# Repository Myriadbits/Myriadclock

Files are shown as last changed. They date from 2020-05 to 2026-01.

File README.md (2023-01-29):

# Myriadclock
16x16 LED word clock with weekday and calender
Multilanguage and fully color customizable.

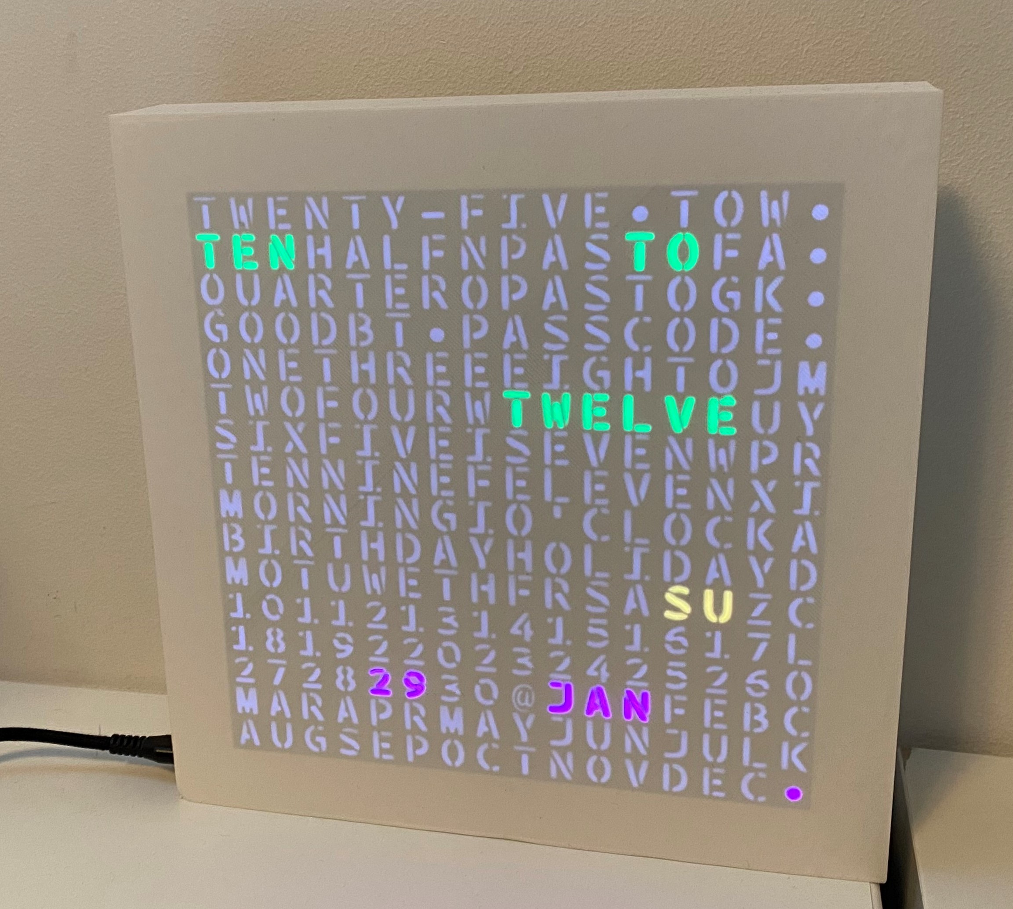
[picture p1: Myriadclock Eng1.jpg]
Englisch clock


## Printing directives
### Grid
*BLACK, PLA, 11 hours, 38 minutes, +- 20 meter (61g)*

Just normal settings, `standard quality`. No need for supports, no infill. Use a brim if desired. Print with the open top of the Y stutts to the top. This way the bottom will be very smooth and there is no light leakage between base plate and the grid.

### Casing
*WHITE, PLA, 18 hours, 13 minutes, +- 44 meter (132g)*

Casing is large (20x20cm) so there might not be space to add the adhesion skirt or brim (at least on my Ender3). So please set `Build plate adhesion type` to `None`. 
To get a nice front panel, it is essential that the `bottom thickness` is at least 4 layers or else you will see the infill instead of the characters in the clock. Set the `top thickness` to 4 as well to avoid seeing the infill at the back of the clock. An infill of 20% is enough. 
Some supports are needed, for the wire hole and the PCB holder. I prefer to set `Support Structure` to `Tree` since the tree's are rather easy to remove.
The casing should be printed in white since the white is partly transparent and will make the characters of the word clock shine through.
Rather obvious, but print the casing with the open part to the top. 
Infill pattern: Cubic, 20%

### Backplane
*WHITE PLA, 9 hours, 50 minutes, +- 27 meter (80g)*

Rotate the backplane UPSIDE-DOWN (flat part down)!
My initial version was printed with only 2 top and 2 bottom layers but that way you can see the infill, so it would be better to just use the default `standard quality`. 
No supports needed, build skirt can be printed.

### Clamp(s)
*3x PLA (Color does not matter), 51 minutes, +- 2 meter (6g)*

Rotate the clamp to it's side top print without supports!
This is used to hold the LED panel on top of the grid, you will probably need 3 clamps. 
Normal print settings, `standard quality` is fine.

### Character plate
*BLACK PLA, 6 hours 34 minutes, +- 8 meter (26g)*

For best result: Print the plate UPSIDE-DOWN. That way the smooth part will be touching the casing.
Print this in black. The plate is only 5 layers tick, all layers should be printed. You might want to tweak some setting to prevent holes getting accidentally be filled with debris/hairs/wires (allthough I didn't find the correct setting for that yet...)
Travel-Combining mode: All
Retract at layer change: True
Z Hop Height: 0.4
Avoid printed parts when travelling: False (I rather not travel over the holes!)

PLA: 105m (for me that is approx €6)

## Components

### LED Panel

WS2812B LED Panel 16x16
Matrix SK6812 WS2812B Panel Flexible 5050 RGB 8x8 8x32 16x16 Pixels Digital Sreen Display Light GyverLamp SP107E LC1000A Kit
https://www.aliexpress.com/item/32875701384.html?spm=a2g0s.9042311.0.0.27424c4dam1nq0
*Buy the WS2812B 16x16 only*

Approx €10 (depends on supplier and shipping fees)

### ESP32 Module
4 MB Flash For WeMos D1 ESP32 ESP-32 ESP-32S ESP32S Wifi Bluetooth Wireless Module Based ESP-WROOM-32 Dual Core Mode CP
https://www.aliexpress.com/item/32917886231.html?spm=a2g0s.9042311.0.0.11af4c4drBH1TU

Approx €4 (depends on supplier and shipping fees)

Total costs (without electricity): +- €20

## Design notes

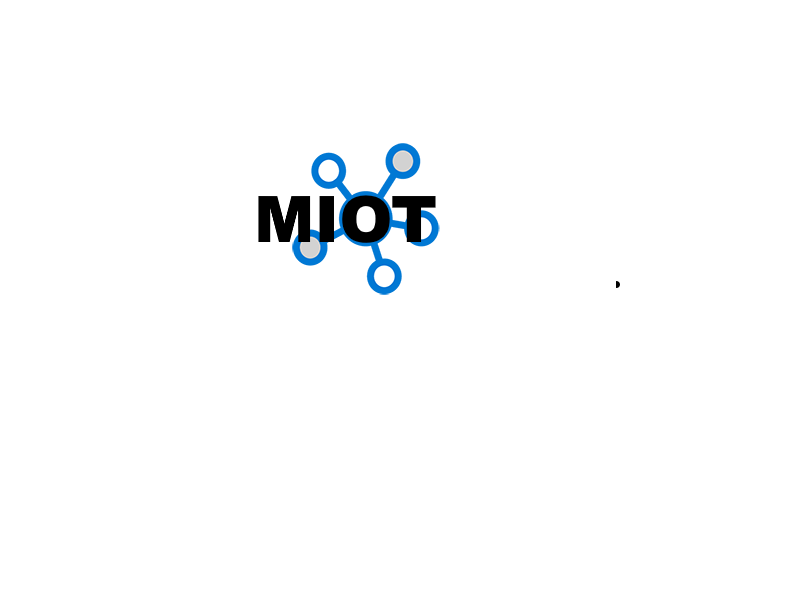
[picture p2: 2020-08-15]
documentation/MIOT.png

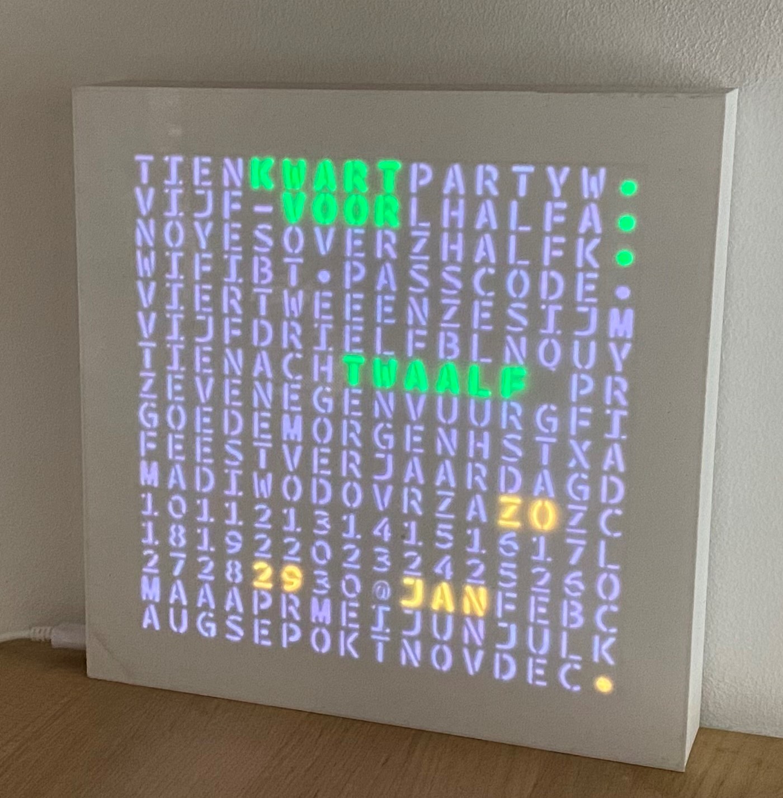
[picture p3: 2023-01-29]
documentation/Myriadclock2.jpg

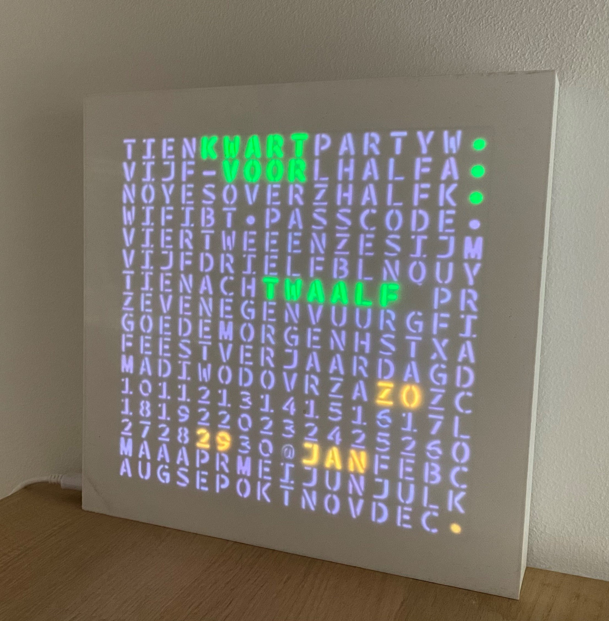
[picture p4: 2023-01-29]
documentation/Myriadclock1.jpg

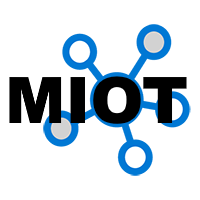
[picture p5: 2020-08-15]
documentation/MIOT2.png

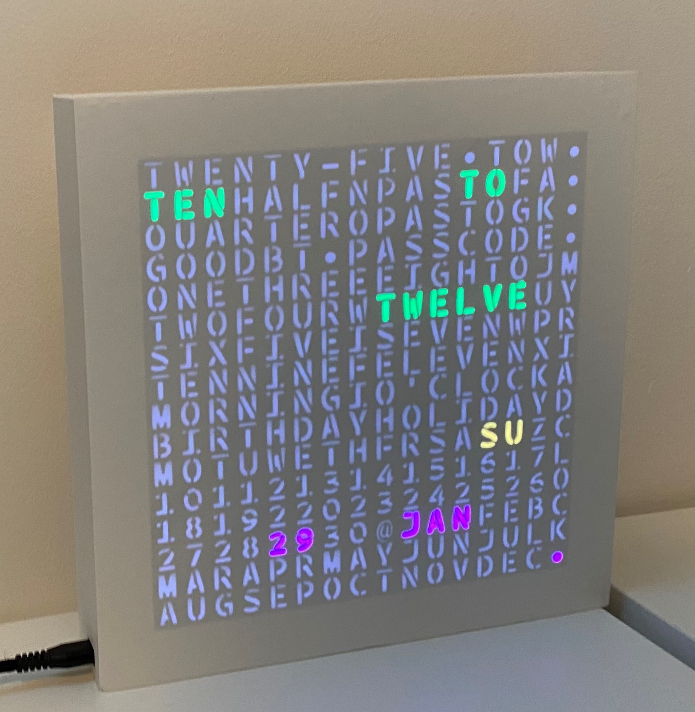
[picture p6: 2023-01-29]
documentation/Myriadclock Eng2.jpg

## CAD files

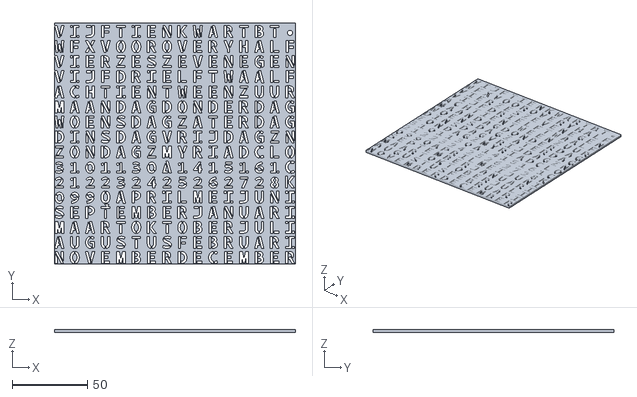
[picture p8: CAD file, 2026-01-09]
stl files/MyriadClock Chars NL v2.stl
160.0 x 160.0 x 2.00

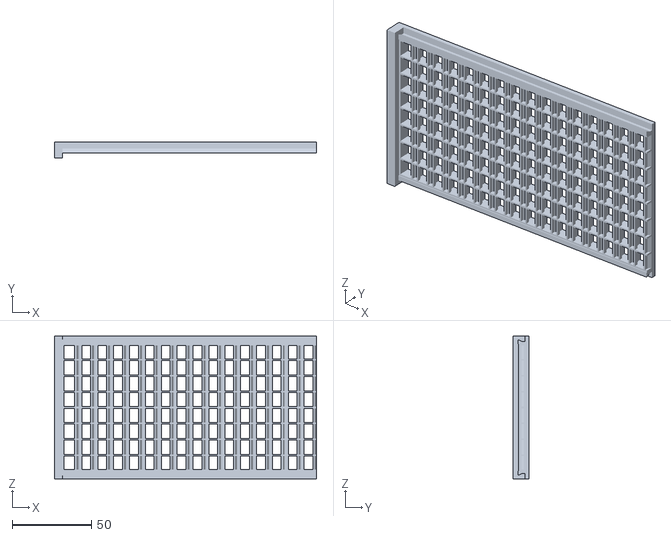
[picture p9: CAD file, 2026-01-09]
stl files/Cloxel_Mask_1.stl
165.0 x 9.90 x 90.0

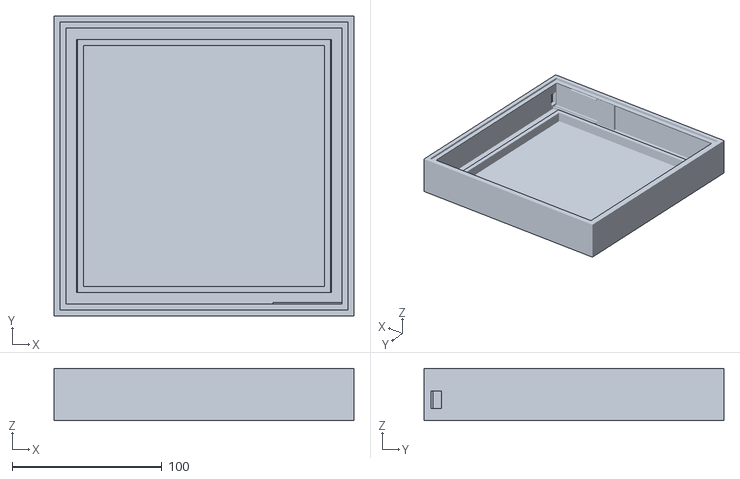
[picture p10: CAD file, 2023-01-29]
stl files/Casing.stl
200.0 x 200.0 x 35.0

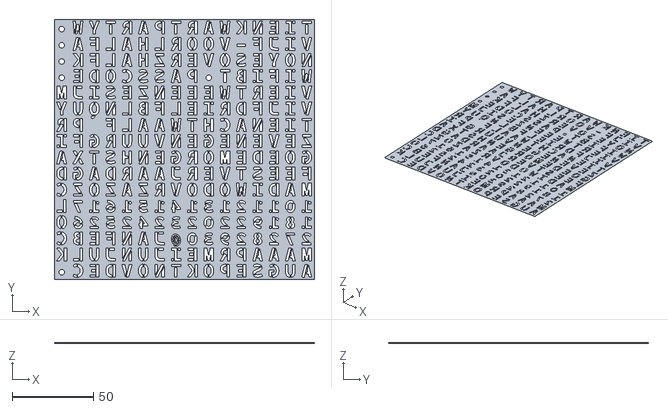
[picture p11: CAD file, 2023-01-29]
stl files/Plate NL V2.01.stl
160.4 x 160.4 x 0.6

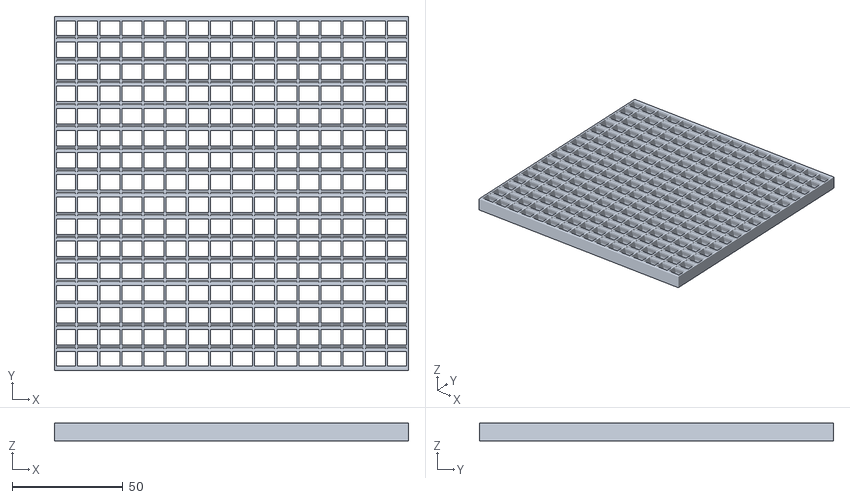
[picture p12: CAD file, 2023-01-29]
stl files/Grid.stl
160.0 x 160.0 x 8.00

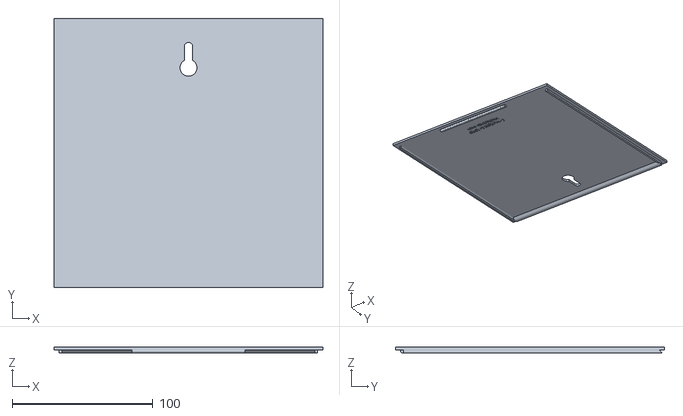
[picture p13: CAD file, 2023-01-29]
stl files/Backplane.stl
191.2 x 191.2 x 4.00

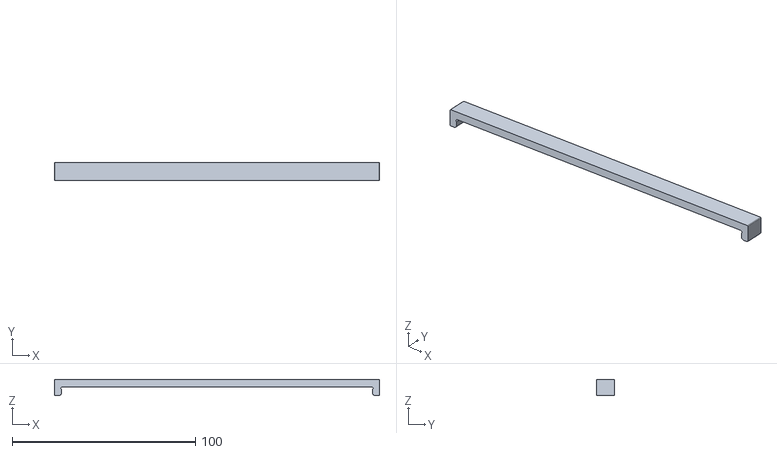
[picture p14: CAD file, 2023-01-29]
stl files/Clamp.stl
177.4 x 10.0 x 8.80

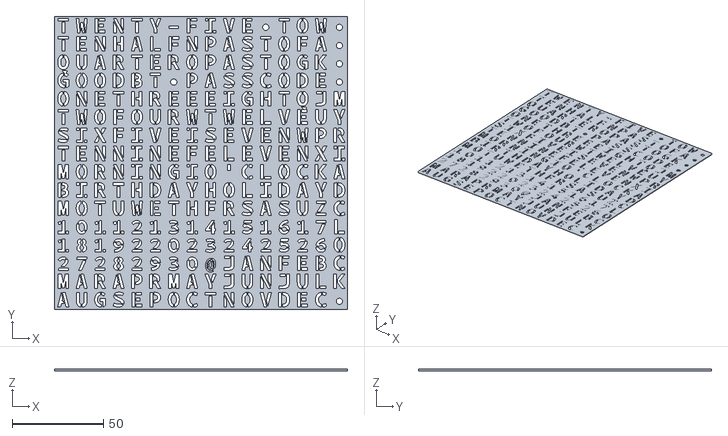
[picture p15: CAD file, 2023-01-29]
stl files/Plate EN V1.01.stl
160.4 x 160.4 x 1.00

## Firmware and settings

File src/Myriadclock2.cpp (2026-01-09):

/*  Myriadclock
    Using WS2812 LED Panel

    Created by Jochem Bakker

    This code is in the public domain...

    You can: copy it, use it, modify it, share it or just plain ignore it!
    Thx!

    NTPClient: https://github.com/arduino-libraries/NTPClient
        //Disabled:    Autoconnect stuff: https://github.com/Hieromon/AutoConnect
    TimeZone: https://github.com/JChristensen/Timezone
    Esp32FOTA: https://github.com/chrisjoyce911/esp32FOTA

    Colors:
    https://sashat.me/2017/01/11/list-of-20-simple-distinct-colors/
*/

#include <NTPClient.h>
#include <WiFi.h>
#include <time.h>
#include <Timezone.h>

#include "../lib/BLEConfig/include/BLEConfig.h"

#include "Console.h"
#define FASTLED_INTERNAL
#include <FastLED.h>       // Fastled library to control the LEDs

#include "DisplayStateManager.h"
#include "MyriadclockConfig.h"
#include <ArduinoJson.h>

#define MYRIADCLOCK_MANUFACTURER    "www.cloxel.nl"
#define MYRIADCLOCK_MODEL           "Wordcloxel"
#define MYRIADCLOCK_VERSION         "2.1.0"
#define MYRIADCLOCK_DEFAULTNAME     "Wordcloxel"
#define MYRIADCLOCK_DEFAULTLOCATION "Default room"


// Pin defines
#define DATA_PIN                13      // Connected to the data pin of the first LED strip
#define RECEIVER_PIN            22      // RXB6 input pin
#define TYPE_PIN                17      // Pin for determining the type of the board
#define NUM_LEDS                256

using namespace std;


static CRGB         g_Leds[NUM_LEDS]; // Define the array of leds
static uint32_t     g_timestamp  = 0;
static uint32_t     g_timeCounter = 0;
static bool         g_fNTPStarted = false;
static int          g_nPreviousHour = 0;

WiFiUDP             g_ntpUDP;

// Manager containing all display state related functionality
DisplayStateManager g_stateManager;

// By default 'pool.ntp.org' is used with 60 seconds update interval and no offset
NTPClient           g_timeClient(g_ntpUDP, "pool.ntp.org");

// The BLE Config library
BLEConfig           g_bleconfig(MYRIADCLOCK_MODEL, MYRIADCLOCK_MANUFACTURER, MYRIADCLOCK_VERSION, 256); // 256 = Clock TODO VERSION

//
// Setup all hardware
//
void setup() 
{
    // Create + start the console
    Console::getInstance().start(115200);   

    // Determine the board type/capabilities
    pinMode(TYPE_PIN, INPUT_PULLDOWN);  // set pin as input
    //Serial.printf("Type: %d\n", digitalRead(TYPE_PIN)); 

	FastLED.addLeds<NEOPIXEL, DATA_PIN>(g_Leds, NUM_LEDS); // Init of the Fastled library
	FastLED.setBrightness(100);  // Don't set it too bright our clock can't handle that power

    // Load/initialize all BLE Config settings
    g_bleconfig.registerWifi(CONFIG_WIFI, "WiFi SSID");

    //g_bleconfig.registerString(CONFIG_LOCATION, "Location", std::string(MYRIADCLOCK_DEFAULTLOCATION), true);

    BLEConfigItemOption *pconfig = g_bleconfig.registerOption(CONFIG_LAYOUT, "Clock layout", 3);
    pconfig->addOption((uint8_t) 0, "Dutch V2");
    pconfig->addOption((uint8_t) 1, "Dutch V1");
    pconfig->addOption((uint8_t) 2, "English"); 
    pconfig->addOption((uint8_t) 3, "Dutch V3");
    pconfig->addOption((uint8_t) 4, "English V2");
    pconfig->addOption((uint8_t) 5, "Cloxel"); 
    
    pconfig = g_bleconfig.registerOption(CONFIG_DAYLIGHTSAVING, "Daylight saving zone", 0);
    pconfig->addOption((uint8_t) 0, "Off"); 
    pconfig->addOption((uint8_t) 1, "Central European"); 
    pconfig->addOption((uint8_t) 2, "United Kingdom"); 
    pconfig->addOption((uint8_t) 3, "Australia");
    pconfig->addOption((uint8_t) 4, "US"); 
      
    pconfig = g_bleconfig.registerOption(CONFIG_TIMEZONE, "Timezone", 13);
    pconfig->addOption((uint8_t) 0, "-12"); 
    pconfig->addOption((uint8_t) 1, "-11"); 
    pconfig->addOption((uint8_t) 2, "-10");
    pconfig->addOption((uint8_t) 3, "-9");
    pconfig->addOption((uint8_t) 4, "-8"); 
    pconfig->addOption((uint8_t) 5, "-7"); 
    pconfig->addOption((uint8_t) 6, "-6"); 
    pconfig->addOption((uint8_t) 7, "-5"); 
    pconfig->addOption((uint8_t) 8, "-4"); 
    pconfig->addOption((uint8_t) 9, "-3"); 
    pconfig->addOption((uint8_t) 10, "-2"); 
    pconfig->addOption((uint8_t) 11, "-1"); 
    pconfig->addOption((uint8_t) 12, "0"); 
    pconfig->addOption((uint8_t) 13, "1"); 
    pconfig->addOption((uint8_t) 14, "2"); 
    pconfig->addOption((uint8_t) 15, "3"); 
    pconfig->addOption((uint8_t) 16, "4"); 
    pconfig->addOption((uint8_t) 17, "5"); 
    pconfig->addOption((uint8_t) 18, "6"); 
    pconfig->addOption((uint8_t) 19, "7"); 
    pconfig->addOption((uint8_t) 20, "8"); 
    pconfig->addOption((uint8_t) 21, "9"); 
    pconfig->addOption((uint8_t) 22, "10"); 
    pconfig->addOption((uint8_t) 23, "11"); 
    pconfig->addOption((uint8_t) 24, "12"); 

    g_bleconfig.registerRGBColor(CONFIG_COLOR_TIME, "Time color", 0x00FF00, true);
    g_bleconfig.registerRGBColor(CONFIG_COLOR_WEEKDAY, "Weekday Color", 0xFFA500, true);
    g_bleconfig.registerRGBColor(CONFIG_COLOR_DATE, "Date color", 0xE59400, true);
    g_bleconfig.registerRGBColor(CONFIG_COLOR_BACKGROUND, "Background color", 0xFFFFFF, true);   

    g_bleconfig.registerSlider(CONFIG_BRIGHTNESS_DAY, "Brightness Day", 80, false);
    g_bleconfig.registerSlider(CONFIG_BRIGHTNESS_NIGHT, "Brightness Night", 30, false);
    g_bleconfig.registerSlider(CONFIG_BRIGHTNESS_BACKGROUND, "Background Brightness", 4, false);

    pconfig = g_bleconfig.registerOption(CONFIG_OPTIONS_TIME, "Time color options", DO_STATIC);
    pconfig->addOption((uint8_t) DO_STATIC, "Manual");
    pconfig->addOption((uint8_t) DO_COLOR_CYCLENORMAL, "Color cycle");
    pconfig->addOption((uint8_t) DO_COLOR_CYCLEHOUR, "Color cycle hourly");
    pconfig->addOption((uint8_t) DO_COLOR_WEEK_AYURVEDA, "Ayurveda colors daily");
    pconfig->addOption((uint8_t) DO_COLOR_WEEK_THAI, "Thai colors daily");

    pconfig = g_bleconfig.registerOption(CONFIG_OPTIONS_WEEKDAY, "Weekday color options", DO_STATIC);
    pconfig->addOption((uint8_t) DO_STATIC, "Manual");
    pconfig->addOption((uint8_t) DO_COLOR_CYCLENORMAL, "Color cycle");
    pconfig->addOption((uint8_t) DO_COLOR_CYCLEHOUR, "Color cycle hourly");
    pconfig->addOption((uint8_t) DO_COLOR_WEEK_AYURVEDA, "Ayurveda colors daily");
    pconfig->addOption((uint8_t) DO_COLOR_WEEK_THAI, "Thai colors daily");

    pconfig = g_bleconfig.registerOption(CONFIG_OPTIONS_DATE, "Date color options", DO_STATIC);
    pconfig->addOption((uint8_t) DO_STATIC, "Manual");
    pconfig->addOption((uint8_t) DO_COLOR_CYCLENORMAL, "Color cycle");
    pconfig->addOption((uint8_t) DO_COLOR_CYCLEHOUR, "Color cycle hourly");
    pconfig->addOption((uint8_t) DO_COLOR_WEEK_AYURVEDA, "Ayurveda colors daily");
    pconfig->addOption((uint8_t) DO_COLOR_WEEK_THAI, "Thai colors daily");

    pconfig = g_bleconfig.registerCommandOption(CONFIG_COMMAND, "Custom commands");
    pconfig->addOption((uint8_t) UC_NORMAL, "Normal");
    pconfig->addOption((uint8_t) UC_MATRIX, "Matrix");
    pconfig->addOption((uint8_t) UC_ALLWORDS, "All words");
    pconfig->addOption((uint8_t) UC_ANALOG, "Analog");

    pconfig = g_bleconfig.registerOption(CONFIG_OPTIONS_CLOXEL, "Cloxel options", 0);
    pconfig->addOption((uint8_t) 0, "Date & time highfont"); 
    pconfig->addOption((uint8_t) 1, "Date & time"); 
    pconfig->addOption((uint8_t) 2, "Time & seconds"); 
    pconfig->addOption((uint8_t) 3, "Date & time & second block"); 
    //g_bleconfig.registerString(CONFIG_NAME, "Name", "enteryourname", false);


    // Start the BLE Config stuff
    // This will also load all previously stored settings
    g_bleconfig.start(&g_stateManager);

    // Initialize all display related functionality
    g_stateManager.initialize(g_Leds, &g_bleconfig);
}


//
// Main program loop
//
void loop() 
{
    // Handle RF 433 Mhz
    //g_rf.loop();   

    // TODO Make currentstate an ENUM
    g_stateManager.handleLoop(g_timeClient.getEpochTime());

    //g_server.handleClient();
        
    // And the console
    Console::getInstance().tick();    

    // Once every x seconds, check the NTP stuff
    uint32_t now = millis();
    if ((now - g_timestamp) > 1000)
    {                
        g_timestamp = now;

        if (WiFi.status() == WL_CONNECTED)
        {
            if (!g_fNTPStarted)
            {
                Serial.printf("Connected to: %s\n", WiFi.SSID().c_str());
                Serial.printf(" - IP address: %s\n", WiFi.localIP().toString().c_str());
                Serial.printf(" - Gateway: %s\n", WiFi.gatewayIP().toString().c_str());
                Serial.printf(" - Mask: %s\n", WiFi.subnetMask().toString().c_str());

                g_timeClient.begin();
                g_fNTPStarted = true;
            }
        }
        else
        {
            g_timeCounter++;
            if ((g_timeCounter % 30) == 0)
            {
                // Not connected anymore, try to reconnect
                Serial.printf("WiFi connection lost. Restarting WiFi\n");
                WiFi.disconnect();
                WiFi.reconnect();
            }
            
            if (g_fNTPStarted)
            {
                g_timeClient.end();
                g_fNTPStarted = false;
            }
        }
        
        if (g_fNTPStarted)
        {
            if (g_timeClient.update())
            {            
                // Check for 3->4 hour switch
                // Let Handle-Loop return another state
                // Convert to local time
                TimeChangeRule *tcr;    
                TimeChangeRule utcRule = {"UTC", Last, Sun, Mar, 1, 0};     // UTC
                Timezone UTC(utcRule);
                time_t t = UTC.toLocal(g_timeClient.getEpochTime(), &tcr); // (Note: tcr cannot be NULL)
                int hours = hour(t);
                int currentYear = year(t);

                if (currentYear > 1970 && g_nPreviousHour != hours)
                {
                    g_stateManager.setDefaultState(DS_CLOCK);
                }

                if (hours == 4 && g_nPreviousHour != 4)
                {
                    // Switch to updating
                    g_stateManager.changeState(DS_UPDATING);
                }
                g_nPreviousHour = hours;
            }
        }
    }   
}

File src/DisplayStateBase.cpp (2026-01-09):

///////////////////////////////////////////////////////////////////////////////
// DisplayStateBase class
// Base class for controlling the display/led states
///////////////////////////////////////////////////////////////////////////////

#include "DisplayStateBase.h"
#include "ClockLayoutNL_V1.h"
#include "Myriadbitsfont5x6_3.h"
#include "Myriadbitsfont5x8_3.h"
#include "HighFont4x8.h"
#include "HighFont4x6.h"

// For now assume the (0,0) of the dutch coordinate system 
#define CLOCK_LATITUDE      52.155194
#define CLOCK_LONGITUDE     5.387270
#define CLOCK_ALTITUDE      10

#define YEAR_2000_TIMESTAMP     946684800ULL
#define SECONDS_PER_HOUR        3600ULL
#define SECONDS_PER_DAY         86400ULL

ledclocklayout_t DisplayStateBase::s_layout = s_layoutNL_V1;

//
//  Return the elapsed time in milliseconds since a timestamp
//
uint32_t DisplayStateBase::Elapsed(uint32_t ts)
{
    uint32_t now = millis();
    if (ts < now) return (now - ts);
    return(now + (0xffffffff - ts));
}

//
// Return the led index in the leds array
//
int16_t DisplayStateBase::CalcLedPos(int8_t x, int8_t y)
{
    int pos = 0;
    if (s_layout.orientation == EOrientation::O_NORMAL)
    {
        if ((y % 2) == 0)
            pos = (s_layout.columns - x - 1) + (y * s_layout.columns); 
        else
            pos = x + (y * s_layout.columns); 
    }
    else
    {
        if ((x % 2) == 0)
            pos = y + (x * s_layout.rows); 
        else
            pos = (s_layout.rows - y - 1) + (x * s_layout.rows); 
    }
    return (pos % s_layout.numLeds);
}

//
// Set the clock layout
void DisplayStateBase::setLayout(const ledclocklayout_t *layout) 
{      
    memcpy(&s_layout, layout, sizeof(s_layout));    
};

//
// Color handler for words
CRGB DisplayStateBase::ColorHandler(CRGB defaultColor, int brightness, int customParam)
{
    return defaultColor.fadeLightBy(255 - brightness);
    //return defaultColor.nscale8_video(brightness);
}

//
// Add a single word to the display/leds
// customParam can be any value, normal operation when ColorHandler is not overriden: customParam is the color
void DisplayStateBase::AddWordToLeds(const ledpos_t *pCurrentWord, CRGB defaultColor, int brightness, int customParam) 
{
    if (pCurrentWord == NULL) return;
    if (m_pLEDs == NULL) return;

    uint8_t charIndex = 0;
    ledpos_t ledPos = pCurrentWord[charIndex];
    while (ledPos.x >= 0 && ledPos.y >= 0)
    {
        // Led numbers are inverted left to right every other row:        
        m_pLEDs[CalcLedPos(ledPos.x, ledPos.y)] = ColorHandler(defaultColor, brightness, customParam);
        
        // Next char
        charIndex++;
        ledPos = pCurrentWord[charIndex];
    }
}

//
// Fill the entire background with a color
void DisplayStateBase::FillBackground(const int brightness)
{
    // Set the background color
    if (brightness != 0)
    {
        CRGB colDefault = m_pConfig->getConfigValue(CONFIG_COLOR_BACKGROUND);

        CRGB rgbClear = ColorHandler(colDefault, brightness, 0);
        for(int n = 0; n < s_layout.numLeds; n++)
            m_pLEDs[n] = rgbClear;
    }
}


//
// @brief  Draw a character on the LED panel
//
void DisplayStateBase::DrawGFX(CRGB *pLEDs, EFontType fontType, ETextAlign align, int x, int y, std::string text, CRGB color)
{
    const GFXfont* pFont = NULL;
    switch (fontType)
    {
        case EFontType::FT_56: pFont = &JochemFont56; break;
        case EFontType::FT_HIGHFONT48: pFont = &Highfont4x8; break;
        case EFontType::FT_HIGHFONT46: pFont = &Highfont4x6; break;
        case EFontType::FT_582: pFont = &JochemFont58; break;
    }
    if (pFont == NULL)
        return;

    int posX = x;
    int posY = y;

    if ((align & ETextAlign::TA_HCENTER) != 0)
    {
        int sizeX = CalculateGFXWidth(pFont, text);
        posX = (s_layout.columns - sizeX) / 2;
    }
    if ((align & ETextAlign::TA_VCENTER) != 0)
    {
        int sizeY = pFont->glyph->height;
        posY = (s_layout.rows - sizeY) / 2;
    }
    if ((align & ETextAlign::TA_MIDTEXT) != 0)
    {
        int len = text.length();
        int sizeX = CalculateGFXWidth(pFont, text.substr(0, len/2));
        if ((len % 2) != 0)
        {
            // Uneven characters, so add half of the width of the center character
            int extra = (CalculateGFXWidth(pFont, text.substr(len/2, 1)) / 2);
            sizeX += extra;
        }
        posX = (s_layout.columns / 2) - sizeX;
    }
    if ((align & ETextAlign::TA_END) != 0)
    {
        int sizeX = CalculateGFXWidth(pFont, text);
        posX = (s_layout.columns - sizeX) - x + 1;
    }

    for(char ch: text)
    {
        if (ch >= pFont->first && ch < pFont->last)
        {
            char c = (ch - pFont->first);

            GFXglyph *glyph = &(pFont->glyph[c]);
            uint8_t *bitmap = pFont->bitmap;

            uint16_t bo = glyph->bitmapOffset;
            uint8_t w = glyph->width;
            uint8_t h = glyph->height;

            uint8_t bits = 0;
            uint8_t bit = 0;
            for (int yy = h - 1; yy >= 0; yy--)
            {
                for (int xx = 0; xx < w; xx++)
                {
                    if (bit == 0x00)
                    {
                        bits = bitmap[bo++];
                        bit = 0x80;
                    }
                    if (bits & bit)
                    {
                        pLEDs[CalcLedPos(posX + xx, posY + y + (h - 1 - yy))] = color;
                    }
                    bit = bit >> 1;
                }
            }
            posX += glyph->xAdvance;
        }
    }
}


/// @brief Calculate the width of an text
/// @param font 
/// @param text 
int DisplayStateBase::CalculateGFXWidth(const GFXfont* font, std::string text)
{
    int16_t xo16 = 0;
    for(char ch: text)
    {
        if (ch >= font->first && ch < font->last)
        {
            char c = (ch - font->first);
            GFXglyph *glyph = &(font->glyph[c]);
            xo16 += glyph->xAdvance;
        }
    }
    return xo16;
}


//
// Simple log function
void DisplayStateBase::log(const char* format, ...)
{
    static char sBuffer[256];
    va_list ap;
    va_start(ap, format);
    Serial.printf("[%s %lu] ", m_name.c_str(), millis());
    vsprintf(sBuffer, format, ap);
    Serial.println(sBuffer);
    va_end(ap);
}
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

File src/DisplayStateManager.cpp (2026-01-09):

///////////////////////////////////////////////////////////////////////////////
// StateManager class
// Class that manages all display states
///////////////////////////////////////////////////////////////////////////////

#include "DisplayStateManager.h"

#include "DisplayStateNoWiFi.h"
#include "DisplayStateBooting.h"
#include "DisplayStateWords.h"
#include "DisplayStateClock.h"
#include "DisplayStateUpdating.h"
#include "DisplayStatePasscode.h"
#include "DisplayStateMatrix.h"
#include "DisplayStateAnalog.h"

#include "ClockLayoutNL_V1.h"
#include "ClockLayoutNL_V2.h"
#include "ClockLayoutNL_V3.h"
#include "ClockLayoutEN_V1.h"
#include "ClockLayoutEN_V2.h"
#include "ClockLayoutNL_Cloxel.h"

#define STARTUP_TIME                10000 // X milliseconds startup time (before switching to no-wifi)
#define TIMEZONE_CHANGED_TIME        5000 // X milliseconds time after switching timezones

// Australia 
TimeChangeRule aEDT = {"AEDT", First, Sun, Oct, 2, 660};    // UTC + 11 hours
TimeChangeRule aEST = {"AEST", First, Sun, Apr, 3, 600};    // UTC + 10 hours

// US 


// UTC
TimeChangeRule utcRule = {"UTC", Last, Sun, Mar, 1, 0};     // UTC


// Fake reset function
void(* resetFunc) (void) = 0;//declare reset function at address 0

//
//  Initialize/setup this class
//
void DisplayStateManager::initialize(CRGB* pLEDs, BLEConfig* pConfig)
{ 
    m_pLEDs = pLEDs;
    m_pTZ = NULL;
    m_pConfig = pConfig;
    m_timezoneChangedCountdown = 0;

    // Add all states to our statemachine
    addState(DS_NOWIFI, new DisplayStateNoWiFi());
    addState(DS_BOOTING, new DisplayStateBooting());
    addState(DS_CLOCK,  new DisplayStateClock());
    addState(DS_WORDS, new DisplayStateWords());
    addState(DS_UPDATING, new DisplayStateUpdating());
    addState(DS_PASSCODE, new DisplayStatePasscode());
    addState(DS_MATRIX, new DisplayStateMatrix());
    addState(DS_ANALOG, new DisplayStateAnalog());

    Console::getInstance().add("state", this, "Switch the display state");
    Console::getInstance().add("layout", this, "Switch the layout");
    Console::getInstance().add("reset", this, "Reset");

    // Start the default state
    changeState(m_eDefaultState);

    // Load the last layout
    setLayout(m_pConfig->getConfigValue(CONFIG_LAYOUT));

    // And initialize the timezone
    setTimezone();
}

//
// Change/set the state
//
void DisplayStateManager::changeState(const EDisplayState eState)
{
    m_eNewState = eState;
}

//
// Add a new state to the state array
//
void DisplayStateManager::addState(EDisplayState eState, DisplayStateBase* pNewState)
{
    pNewState->Initialize(m_pLEDs, m_pConfig, this);
    m_states.insert(std::pair<EDisplayState, DisplayStateBase*>(eState, pNewState));
}

//
// A command is called
//
void DisplayStateManager::commandHandler(std::string command, std::vector<std::string> args)
{
    if (command == "state" && args.size() > 0)
    {
        // Find the name of the command in the state array
        for (auto const& it : m_states)
        {
            if (args[1] == it.second->getName())
            {
                // Found it, change the state
                changeState(it.first);
                break;
            }
        }
    }
    else if (command == "layout" && args.size() > 0)
    {
        int value = atoi(args[1].c_str());

        if (m_pConfig != NULL)
        {
            BLEConfigItemUInt32* pItem = (BLEConfigItemUInt32*) m_pConfig->getConfigItem(CONFIG_LAYOUT);
            if (pItem != NULL)
                pItem->setValue(value); // Change the layout value
            m_pConfig->store();
        }        
        setLayout(value);
    }
    else if (command == "reset")
    {
        resetFunc();
    }
}


//
// Set the clock layout
void DisplayStateManager::setLayout(const int nIndex) 
{   
    // Default is new dutch layout
    ledclocklayout_t *playout = const_cast<ledclocklayout_t*>(&s_layoutNL_V2);

    // Get the correct layout
    if (nIndex == 1) playout = const_cast<ledclocklayout_t*>(&s_layoutNL_V1);
    if (nIndex == 2) playout = const_cast<ledclocklayout_t*>(&s_layoutEN_V1);
    if (nIndex == 3) playout = const_cast<ledclocklayout_t*>(&s_layoutNL_V3);
    if (nIndex == 4) playout = const_cast<ledclocklayout_t*>(&s_layoutEN_V2);
    if (nIndex == 5) playout = const_cast<ledclocklayout_t*>(&s_layoutCloxel); 
    m_isCloxel = playout->pixelDisplay;
    
    // Inform all display states of the new layout
    DisplayStateBase::setLayout(playout);    
}


//
// Set the clock layout
void DisplayStateManager::setTimezone() 
{   
    // Get the timezone
    m_timezoneChangedCountdown = millis() + TIMEZONE_CHANGED_TIME;
    int timezone = m_pConfig->getConfigValue(CONFIG_TIMEZONE);
    timezone -= 12;

    // Calculate Daylight saving time
    delete m_pTZ;
    m_pTZ = NULL;
    switch (m_pConfig->getConfigValue(CONFIG_DAYLIGHTSAVING))
    {
        default:
        case 0: // Off
            {
                TimeChangeRule utcRule = {"UTC", Last, Sun, Mar, 1, (timezone * 60)};     // UTC
                m_pTZ = new Timezone(utcRule);
            }
            break;
        case 1: // Central European
            {
                TimeChangeRule CEST = {"CEST", Last, Sun, Mar, 2, (timezone * 60) + 60}; // Central European Summer Time
                TimeChangeRule CET = {"CET ", Last, Sun, Oct, 3, (timezone * 60)}; // Central European Standard Time
                m_pTZ = new Timezone(CEST, CET);
            }
            break;
        case 2: // United Kingdom
            {
                TimeChangeRule BST = {"BST", Last, Sun, Mar, 1, (timezone * 60) + 60}; // British Summer Time
                TimeChangeRule GMT = {"GMT", Last, Sun, Oct, 2, (timezone * 60)}; // Standard Time
                m_pTZ = new Timezone(BST, GMT);
            }
            break;
        case 3: // Australia
            {
                TimeChangeRule aEDT = {"AEDT", First, Sun, Oct, 2, (timezone * 60)}; // UTC + 11 hours
                TimeChangeRule aEST = {"AEST", First, Sun, Apr, 3, (timezone * 60) - 60}; // UTC + 10 hours
                m_pTZ = new Timezone(aEDT, aEST);
            }
            break;
        case 4: // US
            {
                TimeChangeRule usEDT = {"EDT", Second, Sun, Mar, 2, (timezone * 60) + 60}; // Eastern Daylight Time = UTC - 4 hours (-240)
                TimeChangeRule usEST = {"EST", First, Sun, Nov, 2, (timezone * 60)}; // Eastern Standard Time = UTC - 5 hours (-300)
                m_pTZ = new Timezone(usEDT, usEST);
            }
            break;
    }
}
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

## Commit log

2020-02-28 Colorhandler implemented. Fixed webpage, Added mDNS.
    [DisplayStateBase.cpp, Myriadclock2.cpp]
2020-03-05 Fixed flash size problem (removed sstream = 151 kB!). Updated includes
    [Console.cpp, DisplayStateBase.cpp]
2020-12-22 - Added support for different front plates
2020-12-24 Added statemanager. Switchable layouts. NL V2 implemented.
    [partitions.csv]
2020-12-28 - Fixed bug in switching states
    [DisplayStateManager.cpp, Myriadclock2.cpp]
2021-01-10 - Fixed bug in english layout - Added all characteristics for config items - Config items can now be written safely through BLE!
    [DisplayStateManager.cpp, Myriadclock2.cpp]
2021-01-25 - Added dates (not working yet) - Added resetFunc - Fixed good/nu bt
    [DisplayStateBase.cpp, DisplayStateManager.cpp]
2021-12-27 Get it up to date again...
    [TXTPlate EN V2.stl, TXTPlate NL V6.stl]
2022-09-12 Fixed reconnecting issue. Disabled security. Removed birthdays.
    [Myriadclock2.cpp]
2022-09-18 Removed synopsis (useless + too much data). Now able to notify that data has changed (needed for WiFi). Wifi SSIDs refreshed every 2 minutes. Fixed disconnect/connect issue. Fixed statemachine NoWifi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
    [DisplayStateBase.cpp, DisplayStateManager.cpp]
2022-09-18 Fixed Fasteled compiler warning. Fixed day-night brightness issue. Inc version.
    [Myriadclock2.cpp]
2022-10-26 Fixed issue with matrix showing up when changing timezone
    [DisplayStateManager.cpp]
2023-01-29 Added correct STL files
    [Backplane.stl, Casing.stl, Clamp.stl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]
2024-02-11 - Updated ESP platform. - Made some changes to WiFi reconnecting (not sure it works) - Removed mainloop bugs (incorrect time comparison) - Added transitons to clock - Needed to move time to word conv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
    [ClockTimeWordConvertor.cpp, DisplayStateBase.cpp]
2024-02-11 Oops, the 9-minute was missing. Fixed it
    [ClockTimeWordConvertor.cpp]
2024-02-14 - Added analog (not finished yet). Fixed bug in V1 that showed incorrect time. Added heart on valentine.
    [ClockTimeWordConvertor.cpp]
2024-10-18 Started with adding support for cloxel
    [Cloxel_Mask_1.stl, MyriadClock Chars NL v2.stl]
2024-10-30 - Fixed bugs in Cloxel. Refactored: Cloxel support now in base classes.
    [DisplayStateBase.cpp]
2026-01-09 Fixed some merge issues
    [DisplayStateManager.cpp, Myriadclock2.cpp]
